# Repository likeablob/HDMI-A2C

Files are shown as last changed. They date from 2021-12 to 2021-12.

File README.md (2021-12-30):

# HDMI-A2C
A simple `HDMI Type A Male` to `mini HDMI (aka HDMI Type C) Male` adapter board.

<p align="center">
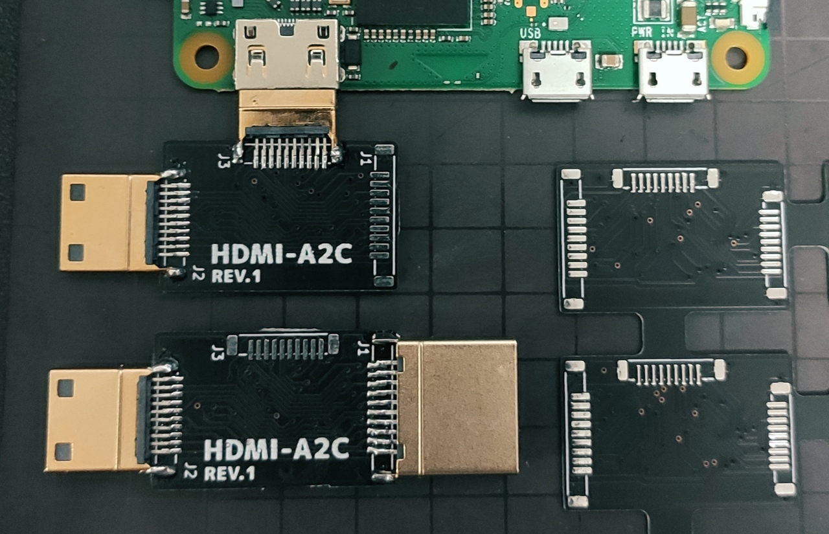
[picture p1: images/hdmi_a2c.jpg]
  
</p>

## BOM
| Name | Quantity | Typ. price (USD) | Notes |
| --- | :---: | --- | --- |
| HDMI (Type A) Male Plug | 1 | 0.2 ~ 0.9 | [See below](#hdmi-type-a-male-plug) |
| mini HDMI (Type C) Male Plug | 1 | 0.3 ~ 1.8 | [See below](#mini-hdmi-type-c-male-plug) |

#### `HDMI (Type A) Male Plug`
- Notes
  - Before soldering, pins on the upper side must be bended slightly, to make the parts "grab" the board of 1 mm thickness. (It expects 1.6 mm of board thickness, however the mini HDMI plug requires 1 mm.)
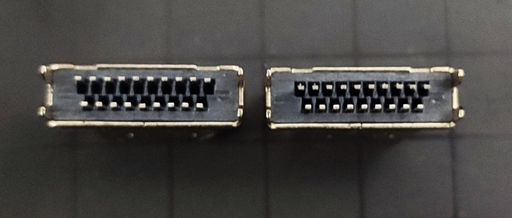
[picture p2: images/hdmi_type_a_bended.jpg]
  
- Data sheets
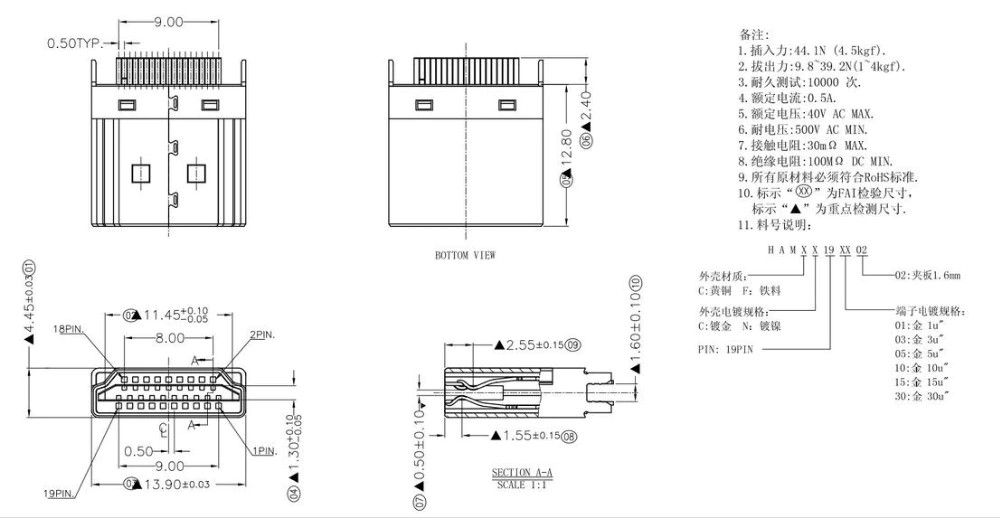
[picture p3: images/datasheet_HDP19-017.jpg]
  -  ([src](https://www.aliexpress.com/item/32963116074.html))
- Sellers
  - Note that the following parts are not the same model exactly, however they are pin-compatible AFAIK.
  - [aitendo HDP19-017](https://www.aitendo.com/product/19008)
  - [Aliexpress 10PCS HDMI Male Jack/plug connector 19PIN 19P 1.6MM 180 Degree Gold-Plated hd 19 PIN](https://www.aliexpress.com/item/32963116074.html)

#### `mini HDMI (Type C) Male Plug`
- Data sheets
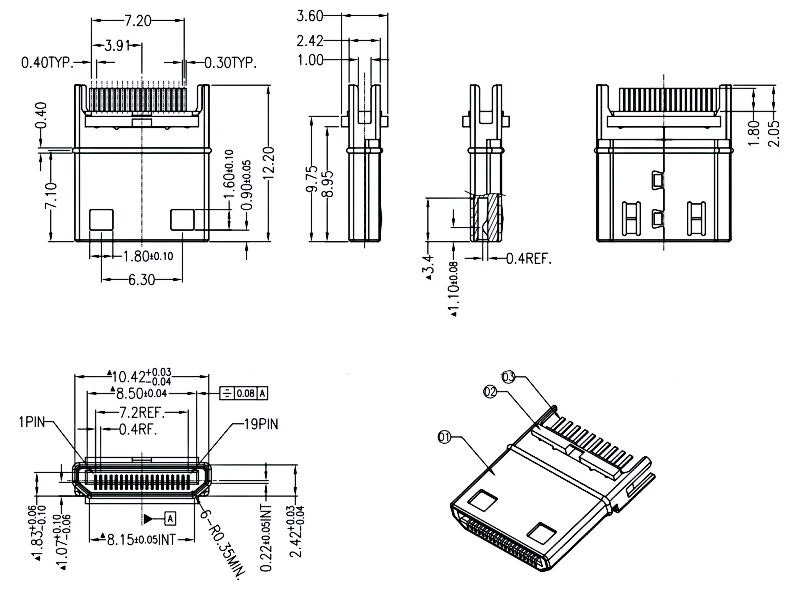
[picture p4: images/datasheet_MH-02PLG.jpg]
  -  ([src](https://www.aliexpress.com/item/32653409668.html))
  - [MH-02PLG.pdf](http://aitendo3.sakura.ne.jp/aitendo_data/product_img/cn/hdmi/MH-02PLG/MH-02PLG.pdf)
- Sellers
  - Note that the following parts are not the same model exactly, however they are pin-compatible AFAIK.
  - [aitendo MH-02PLG](https://www.aitendo.com/product/19500)
  - [Aliexpress cltgxdd Gold plating 19 PiN male plug C Type HDMI Jack Splint Type,HDMI repair replacement](https://www.aliexpress.com/item/32863394130.html)

## PCB
- Required specs
  - **PCB Thickness: 1mm**
    - This is required for the mini HDMI plug.
  - Layers: 2
  - PCB & Silkscreen color: Black and white, but choose anything you like.
- Gerber
  - See zip files under [./gerber](./gerber).
  - [`hdmi_a2c_rev1_panelized_3x4.zip`](./gerber/hdmi_a2c_rev1_panelized_3x4.zip) is a panelized one.
    - Credit: It was made with [This is Not Rocket Science]'s Gerber Panelizer.
  - Or just use KiCad v5 to generate files.
- For reference, I ordered the REV.1 board from JLCPCB in this time.

## Changelog
- REV.1
  - Initial release
  - Known issues:
    - `HDMI_A_HDP19-017_Horizontal.kicad_mod`: Though it's solderble, its pad pitch is a little narrower than the actual (0.5 mm).

## License
MIT

## Related projects
- ~~LandscaPi~~ TBD
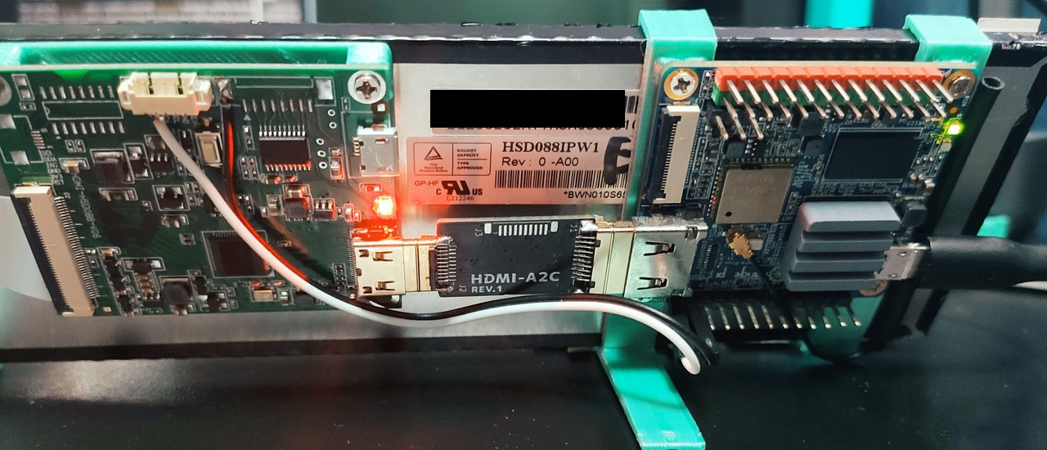
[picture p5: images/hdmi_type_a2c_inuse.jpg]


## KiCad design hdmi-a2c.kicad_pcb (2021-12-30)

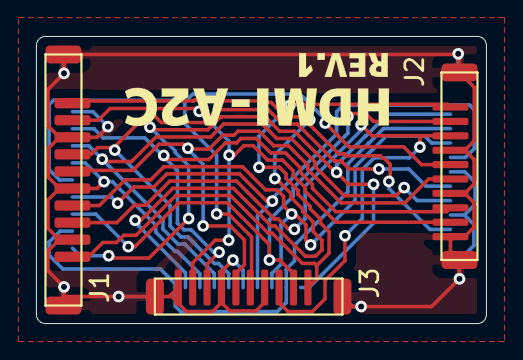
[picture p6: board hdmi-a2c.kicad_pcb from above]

Board: 2 copper layers, 25.0 x 16.0 mm, 3 parts (0 on the bottom side), 15 nets.

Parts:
J1: HDMI_A; HDMI_A_HDP19-017_Horizontal
J2, J3: HDMI_C_1.3; HDMI_C_MH-02PLG_Horizontal

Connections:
GND: J1.2, J1.5, J1.8, J1.11, J1.17, J1.SH, J2.1, J2.4, J2.7, J2.10, J2.13, J2.SH, J3.1, J3.4, J3.7, J3.10, J3.13, J3.SH
HDMI_+5V: J1.18, J2.18, J3.18
HDMI_CEC: J1.13, J2.14, J3.14
HDMI_CK+: J1.10, J2.11, J3.11
HDMI_CK-: J1.12, J2.12, J3.12
HDMI_D0+: J1.7, J2.8, J3.8
HDMI_D0-: J1.9, J2.9, J3.9
HDMI_D1+: J1.4, J2.5, J3.5
HDMI_D1-: J1.6, J2.6, J3.6
HDMI_D2+: J1.1, J2.2, J3.2
HDMI_D2-: J1.3, J2.3, J3.3
HDMI_HPD: J1.19, J2.19, J3.19
HDMI_SCL: J1.15, J2.15, J3.15
HDMI_SDA: J1.16, J2.16, J3.16
HDMI_UTILITY: J1.14, J2.17, J3.17
